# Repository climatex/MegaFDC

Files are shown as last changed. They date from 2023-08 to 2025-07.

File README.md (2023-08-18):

# MegaFDC
Arduino Mega2560 floppy disk controller.

Supports 8" / 5.25" / 3.5" drives (PS/2 2.88MB included) with custom geometry, FAT12 and experimental CP/M.

Interfaces via USB/RS232, also through keyboard and display.

# More information
Check out my [website article](http://boginjr.com/it/hw/megafdc) to learn more!

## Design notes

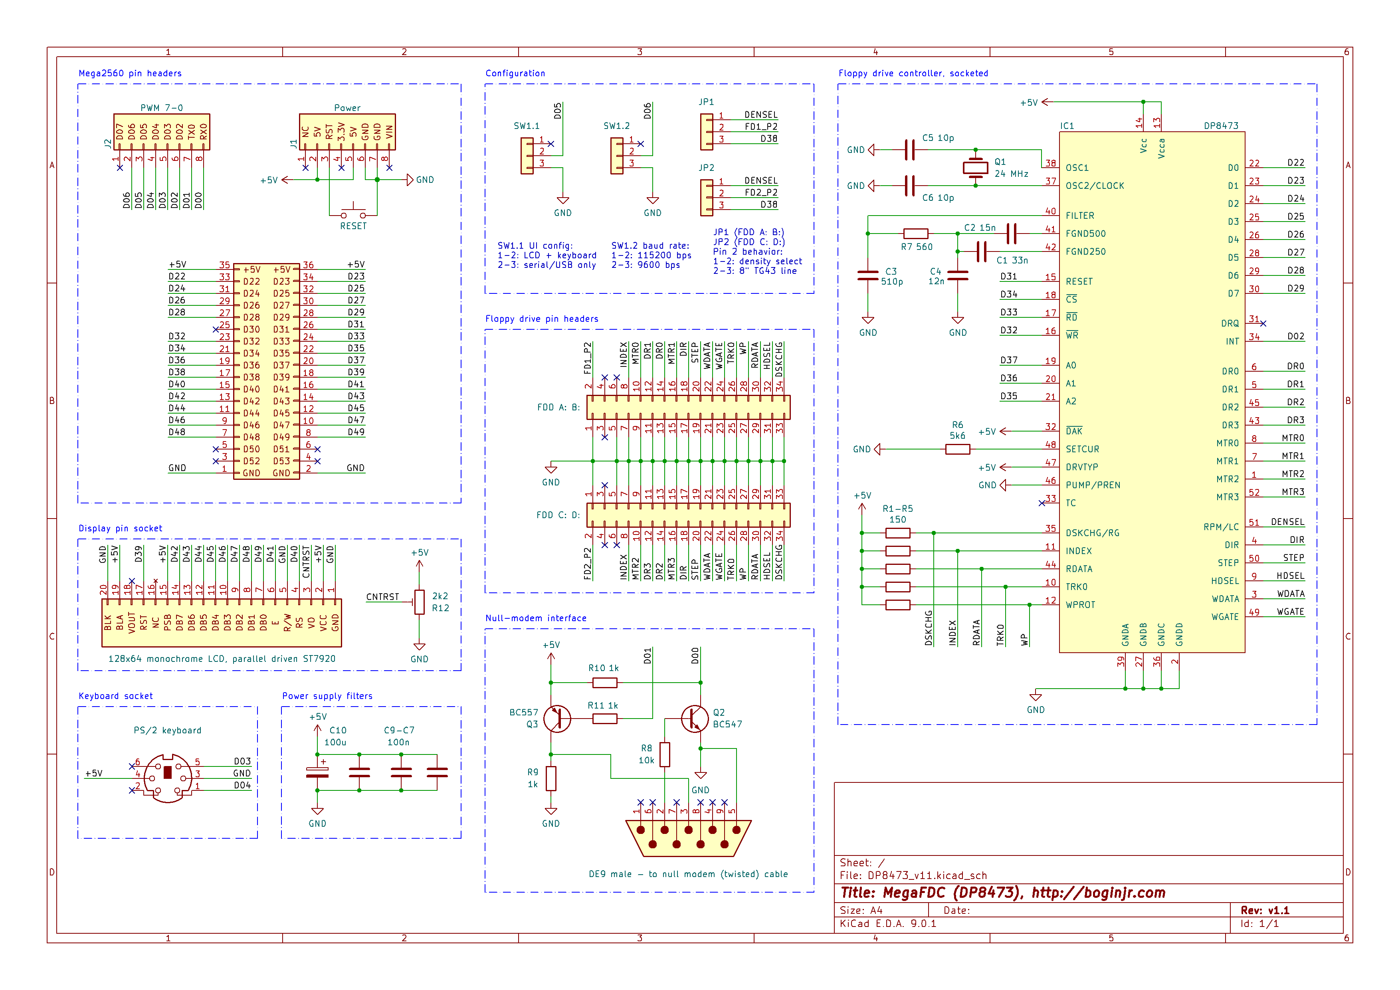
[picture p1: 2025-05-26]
Boards/DP8473/DP8473_v11.png

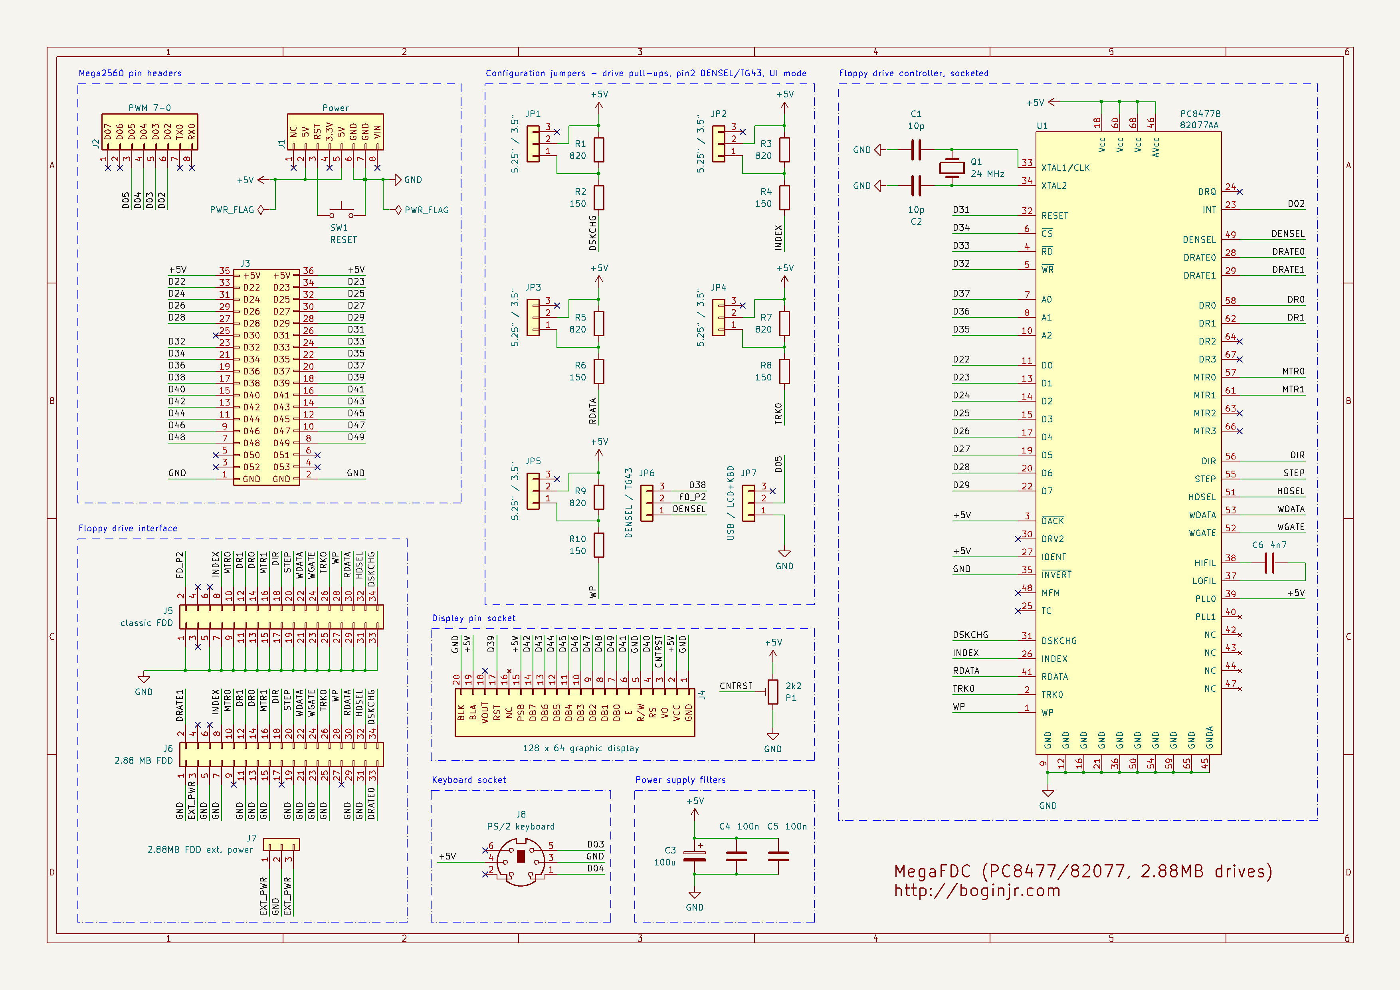
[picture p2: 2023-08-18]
Boards/PC8477/PC8477.png

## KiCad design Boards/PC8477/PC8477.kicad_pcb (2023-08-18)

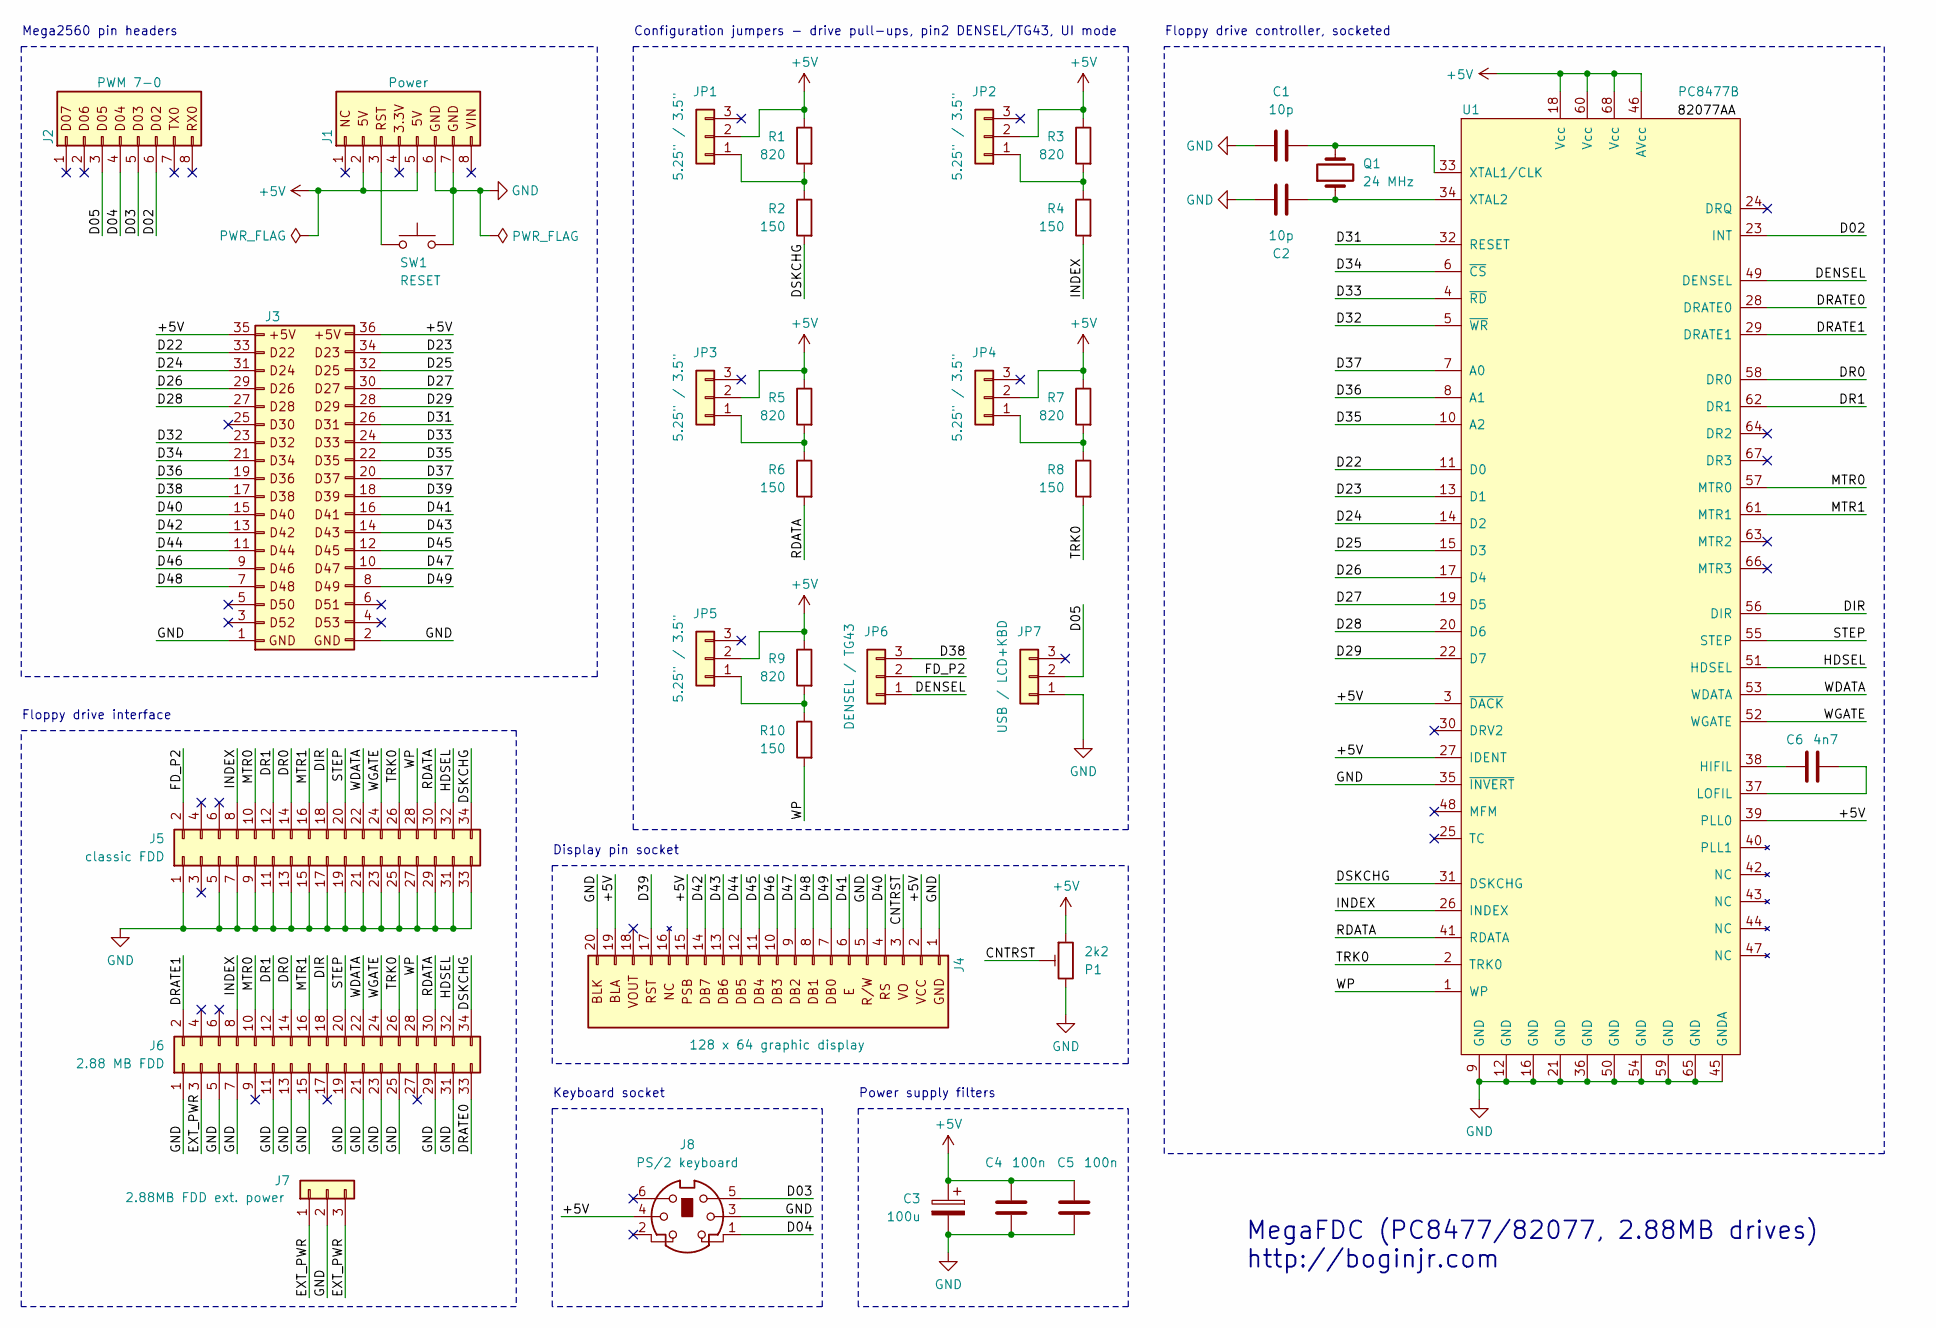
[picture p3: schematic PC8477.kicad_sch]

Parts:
C1, C2: 10p; C_Disc_D7.5mm_W2.5mm_P5.00mm
C3: 100u; CP_Radial_D6.3mm_P2.50mm
C4, C5: 100n; C_Disc_D7.5mm_W2.5mm_P5.00mm
C6: 4n7; C_Disc_D7.5mm_W2.5mm_P5.00mm
J1: Power; PinHeader_1x08_P2.54mm_Vertical
J2: PWM 7-0; PinHeader_1x08_P2.54mm_Vertical
J3: Digital; PinHeader_2x18_P2.54mm_Vertical
J4: 128 x 64 graphic display; PinSocket_1x20_P2.54mm_Vertical
J5: classic FDD; PinHeader_2x17_P2.54mm_Vertical
J6: 2.88 MB FDD; PinHeader_2x17_P2.54mm_Vertical
J7: 2.88MB FDD ext. power; PinHeader_1x03_P2.54mm_Vertical
J8: PS/2 keyboard; Mini_DIN6_Female_THT
JP1, JP2, JP3, JP4, JP5: 5.25" / 3.5"; PinHeader_1x03_P2.54mm_Vertical
JP6: DENSEL / TG43; PinHeader_1x03_P2.54mm_Vertical
JP7: USB / LCD+KBD; PinHeader_1x03_P2.54mm_Vertical
P1: 2k2; Potentiometer_Bourns_3386P_Vertical
Q1: 24 MHz; Crystal_HC49-U_Vertical
R1, R3, R5, R7, R9: 820; R_Axial_DIN0207_L6.3mm_D2.5mm_P10.16mm_Horizontal
R2, R4, R6, R8, R10: 150; R_Axial_DIN0207_L6.3mm_D2.5mm_P10.16mm_Horizontal
SW1: RESET; SW_PUSH_6mm
U1: PC8477B; PLCC-68_THT-Socket

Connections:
+5V: C3.1, C4.1, C5.1, J1.2, J1.5, J3.35, J3.36, J4.2, J4.15, J4.19, J8.4, JP1.2, JP2.2, JP3.2, JP4.2, JP5.2, P1.1, R1.1, R3.1, R5.1, R7.1, R9.1, U1.3 (~DACK), U1.18 (Vcc), U1.27 (IDENT), U1.39 (PLL0), U1.46 (AVcc), U1.60 (Vcc), U1.68 (Vcc)
/CNTRST: J4.3, P1.2
/D02: J2.6, U1.23 (INT)
/D03: J2.5, J8.5
/D04: J2.4, J8.1
/D05: J2.3, JP7.2
/D22: J3.33, U1.11 (D0)
/D23: J3.34, U1.13 (D1)
/D24: J3.31, U1.14 (D2)
/D25: J3.32, U1.15 (D3)
/D26: J3.29, U1.17 (D4)
/D27: J3.30, U1.19 (D5)
/D28: J3.27, U1.20 (D6)
/D29: J3.28, U1.22 (D7)
/D31: J3.26, U1.32 (RESET)
/D32: J3.23, U1.5 (~WR)
/D33: J3.24, U1.4 (~RD)
/D34: J3.21, U1.6 (~CS)
/D35: J3.22, U1.10 (A2)
/D36: J3.19, U1.8 (A1)
/D37: J3.20, U1.7 (A0)
/D38: J3.17, JP6.3
/D39: J3.18, J4.17
/D40: J3.15, J4.4
/D41: J3.16, J4.6
/D42: J3.13, J4.14
/D43: J3.14, J4.13
/D44: J3.11, J4.12
/D45: J3.12, J4.11
/D46: J3.9, J4.10
/D47: J3.10, J4.9
/D48: J3.7, J4.8
/D49: J3.8, J4.7
/DENSEL: JP6.1, U1.49 (DENSEL)
/DIR: J5.18, J6.18, U1.56 (DIR)
/DR0: J5.14, J6.14, U1.58 (DR0)
/DR1: J5.12, J6.12, U1.62 (DR1)
/DRATE0: J6.33, U1.28 (DRATE0)
/DRATE1: J6.2, U1.29 (DRATE1)
/DSKCHG: J5.34, J6.34, R2.2, U1.31 (DSKCHG)
/EXT_PWR: J6.3, J7.1, J7.3
/FD_P2: J5.2, JP6.2
/HDSEL: J5.32, J6.32, U1.51 (HDSEL)
/INDEX: J5.8, J6.8, R4.2, U1.26 (INDEX)
/MTR0: J5.10, J6.10, U1.57 (MTR0)
/MTR1: J5.16, J6.16, U1.61 (MTR1)
/RDATA: J5.30, J6.30, R6.2, U1.41 (RDATA)
/STEP: J5.20, J6.20, U1.55 (STEP)
/TRK0: J5.26, J6.26, R8.2, U1.2 (TRK0)
/WDATA: J5.22, J6.22, U1.53 (WDATA)
/WGATE: J5.24, J6.24, U1.52 (WGATE)
/WP: J5.28, J6.28, R10.2, U1.1 (WP)
GND: C1.1, C2.1, C3.2, C4.2, C5.2, J1.6, J1.7, J3.1, J3.2, J4.1, J4.5, J4.20, J5.1, J5.5, J5.7, J5.9, J5.11, J5.13, J5.15, J5.17, J5.19, J5.21, J5.23, J5.25, J5.27, J5.29, J5.31, J5.33, J6.1, J6.5, J6.7, J6.11, J6.13, J6.15, J6.19, J6.21, J6.23, J6.25, J6.29, J6.31, J7.2, J8.3, J8.SH1, J8.SH2, J8.SH3, JP7.1, P1.3, SW1.1, U1.9 (GND), U1.12 (GND), U1.16 (GND), U1.21 (GND), U1.35 (~INVERT), U1.36 (GND), U1.45 (GNDA), U1.50 (GND), U1.54 (GND), U1.59 (GND), U1.65 (GND)
unnamed: J1.3, SW1.2
unnamed: JP1.1, R1.2, R2.1
unnamed: JP2.1, R3.2, R4.1
unnamed: JP3.1, R5.2, R6.1
unnamed: JP4.1, R7.2, R8.1
unnamed: JP5.1, R9.2, R10.1
unnamed: C6.2, U1.38 (HIFIL)
unnamed: C6.1, U1.37 (LOFIL)
unnamed: C1.2, Q1.2, U1.33 (XTAL1/CLK)
unnamed: C2.2, Q1.1, U1.34 (XTAL2)

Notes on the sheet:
Configuration jumpers - drive pull-ups, pin2 DENSEL/TG43, UI mode
Keyboard socket
Floppy drive interface
Power supply filters
MegaFDC (PC8477/82077, 2.88MB drives) http://boginjr.com
Display pin socket
Floppy drive controller, socketed
Mega2560 pin headers

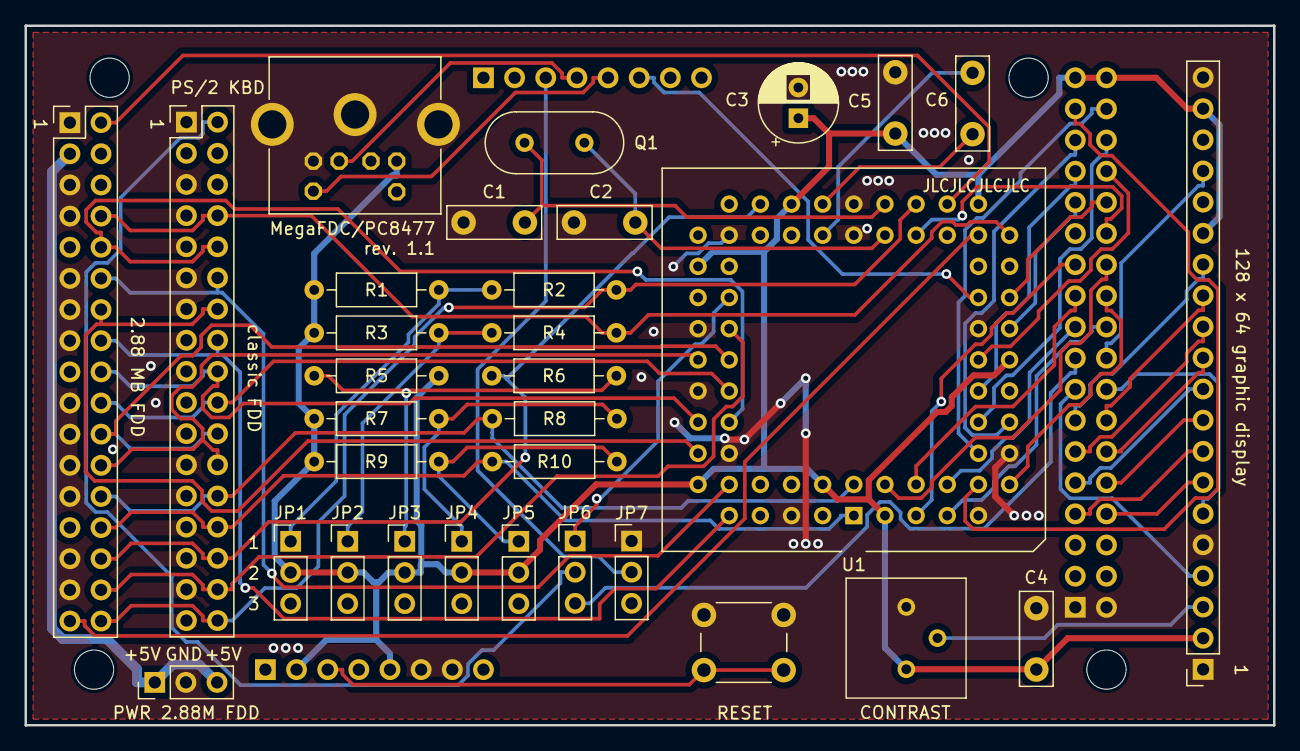
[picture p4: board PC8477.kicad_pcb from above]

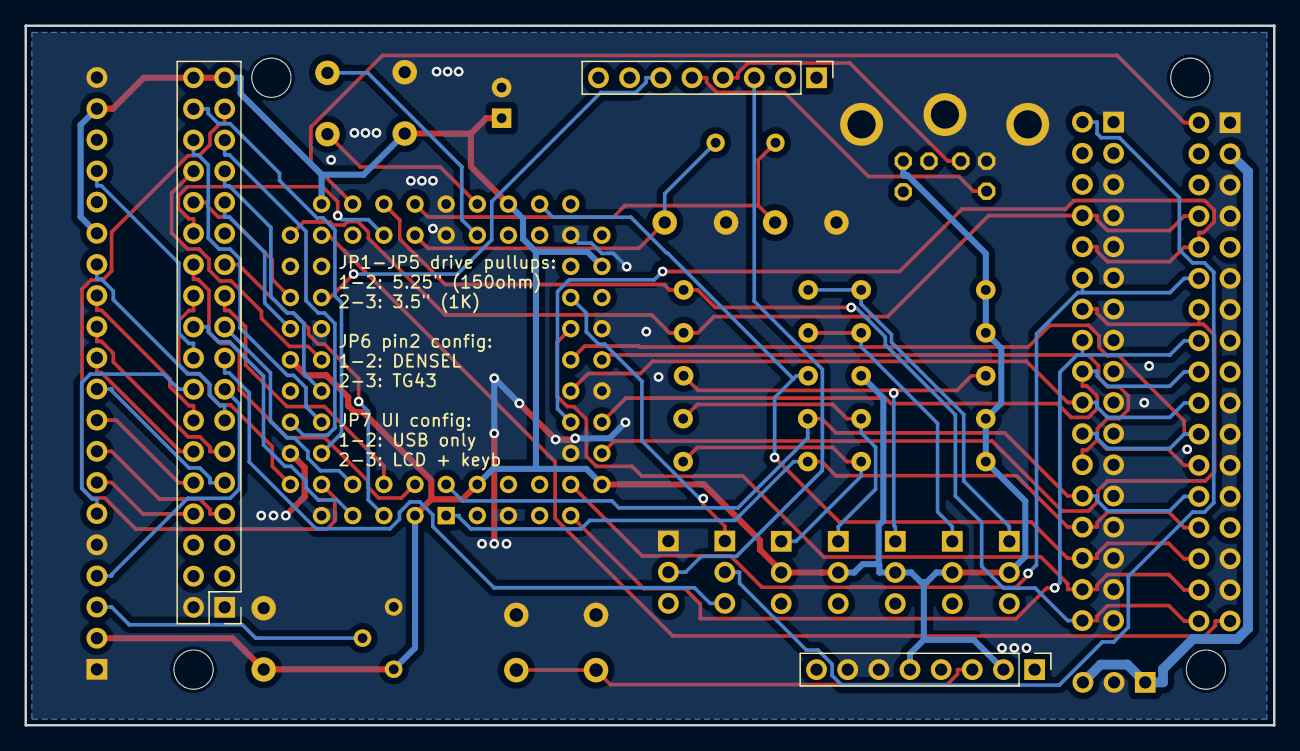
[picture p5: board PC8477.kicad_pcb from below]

Board: 2 copper layers, 101.8 x 57.0 mm, 39 parts (3 on the bottom side), 63 nets.

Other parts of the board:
MH1, MH2, MH5, MH6: MountingHole_3.2mm

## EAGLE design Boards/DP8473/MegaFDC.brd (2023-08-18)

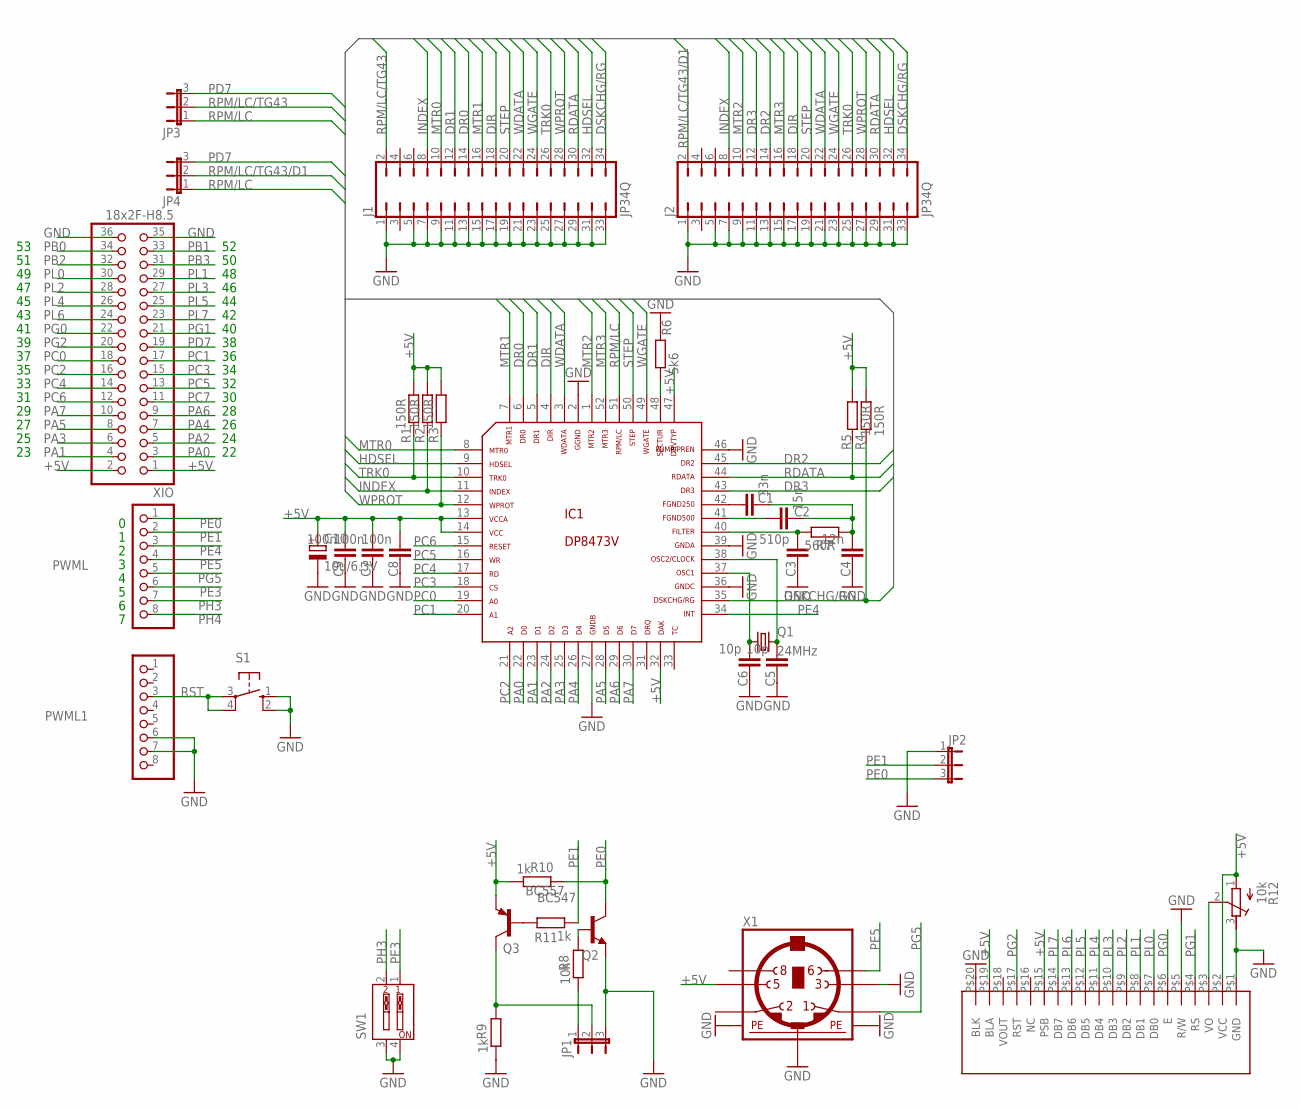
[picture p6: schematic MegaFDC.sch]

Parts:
C1: 33n; C025-025X050
C2: 15n; C025-025X050
C3: 510p; C025-025X050
C4: 12n; C025-025X050
C5, C6: 10p; C025-025X050
C7, C8, C9: 100n; C050-025X075
C10: 10u/6.3V; B45181A
IC1: DP8473V; S52
J1, J2: JP34Q
JP1, JP2, JP3, JP4: JP2E; JP2
PWML, PWML1: 8x1F-H8.5; 1X08
Q1: 24MHz; HC49/S
Q2: BC547; TO92S
Q3: BC557; TO92-EBC
R1, R2, R3, R4, R5: 150R; 0207/7
R6: 5k6; 0207/7
R7: 560R; 0207/7
R8: 10k; 0207/7
R9, R10, R11: 1k; 0207/7
R12: 10k; RTRIM3296Y
S1: 10-XX; B3F-10XX
SW1: DIP2X; EDG-02
U$1: W12864
X1: MINI_DIN_6; M_DIN6
XIO: 18x2F-H8.5; 2X18

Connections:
+5V: C7.2, C8.2, C9.2, C10.+, IC1.13, IC1.14, IC1.32, IC1.47, Q3.E, R1.2, R2.2, R3.2, R4.2, R5.2, R10.1, R12.1 (A), U$1.P$2 (VCC), U$1.P$15 (PSB), U$1.P$19 (BLA), X1.5, XIO.1, XIO.2
DIR: IC1.4, J1.18, J2.18
DR0: IC1.6, J1.14
DR1: IC1.5, J1.12
DR2: IC1.45, J2.14
DR3: IC1.43, J2.12
DSKCHG/RG: IC1.35, J1.34, J2.34, R4.1
GND: C3.1, C4.1, C5.1, C6.1, C7.1, C8.1, C9.1, C10.-, IC1.2, IC1.27, IC1.36, IC1.39, IC1.46, J1.1, J1.5, J1.7, J1.9, J1.11, J1.13, J1.15, J1.17, J1.19, J1.21, J1.23, J1.25, J1.27, J1.29, J1.31, J1.33, J2.1, J2.5, J2.7, J2.9, J2.11, J2.13, J2.15, J2.17, J2.19, J2.21, J2.23, J2.25, J2.27, J2.29, J2.31, J2.33, JP1.3, JP2.1, PWML1.6, PWML1.7, Q2.1 (E), R6.2, R9.1, R12.3 (E), S1.1 (S), S1.2 (S1), SW1.3, SW1.4, U$1.P$1 (GND), U$1.P$5 (R/W), U$1.P$20 (BLK), X1.3, X1.SH1 (PE1), X1.SH2 (PE2), X1.SH3 (PE3), XIO.35, XIO.36
HDSEL: IC1.9, J1.32, J2.32
INDEX: IC1.11, J1.8, J2.8, R2.1
MTR0: IC1.8, J1.10
MTR1: IC1.7, J1.16
MTR2: IC1.1, J2.10
MTR3: IC1.52, J2.16
unnamed: C1.1, IC1.42
unnamed: C2.1, IC1.41
unnamed: C1.2, C2.2, C4.2, R7.2
unnamed: C3.2, IC1.40, R7.1
unnamed: C5.2, IC1.38, Q1.2
unnamed: IC1.48, R6.1
unnamed: C6.2, IC1.37, Q1.1
unnamed: JP1.1, R8.1
unnamed: Q2.2 (B), R8.2
unnamed: JP1.2, Q3.C, R9.2
unnamed: Q3.B, R11.2
unnamed: R12.2 (S), U$1.P$3 (VO)
PA0: IC1.22, XIO.3
PA1: IC1.23, XIO.4
PA2: IC1.24, XIO.5
PA3: IC1.25, XIO.6
PA4: IC1.26, XIO.7
PA5: IC1.28, XIO.8
PA6: IC1.29, XIO.9
PA7: IC1.30, XIO.10
PB0: XIO.34
PB1: XIO.33
PB2: XIO.32
PB3: XIO.31
PC0: IC1.19, XIO.18
PC1: IC1.20, XIO.17
PC2: IC1.21, XIO.16
PC3: IC1.18, XIO.15
PC4: IC1.17, XIO.14
PC5: IC1.16, XIO.13
PC6: IC1.15, XIO.12
PC7: XIO.11
PD7: JP3.3, JP4.3, XIO.19
PE0: JP2.3, PWML.1, Q2.3 (C), R10.2
PE1: JP2.2, PWML.2, R11.1
PE3: PWML.6, SW1.1
PE4: IC1.34, PWML.3
PE5: PWML.4, X1.6
PG0: U$1.P$6 (E), XIO.22
PG1: U$1.P$4 (RS), XIO.21
PG2: U$1.P$17 (RST), XIO.20
PG5: PWML.5, X1.1
PH3: PWML.7, SW1.2
PH4: PWML.8
PL0: U$1.P$7 (DB0), XIO.30
PL1: U$1.P$8 (DB1), XIO.29
PL2: U$1.P$9 (DB2), XIO.28
PL3: U$1.P$10 (DB3), XIO.27
PL4: U$1.P$11 (DB4), XIO.26
PL5: U$1.P$12 (DB5), XIO.25
PL6: U$1.P$13 (DB6), XIO.24
PL7: U$1.P$14 (DB7), XIO.23
RDATA: IC1.44, J1.30, J2.30, R5.1
RPM/LC: IC1.51, JP3.1, JP4.1
RPM/LC/TG43: J1.2, JP3.2
RPM/LC/TG43/D1: J2.2, JP4.2
RST: PWML1.3, S1.3, S1.4 (P1)
STEP: IC1.50, J1.20, J2.20
TRK0: IC1.10, J1.26, J2.26, R1.1
WDATA: IC1.3, J1.22, J2.22
WGATE: IC1.49, J1.24, J2.24
WPROT: IC1.12, J1.28, J2.28, R3.1

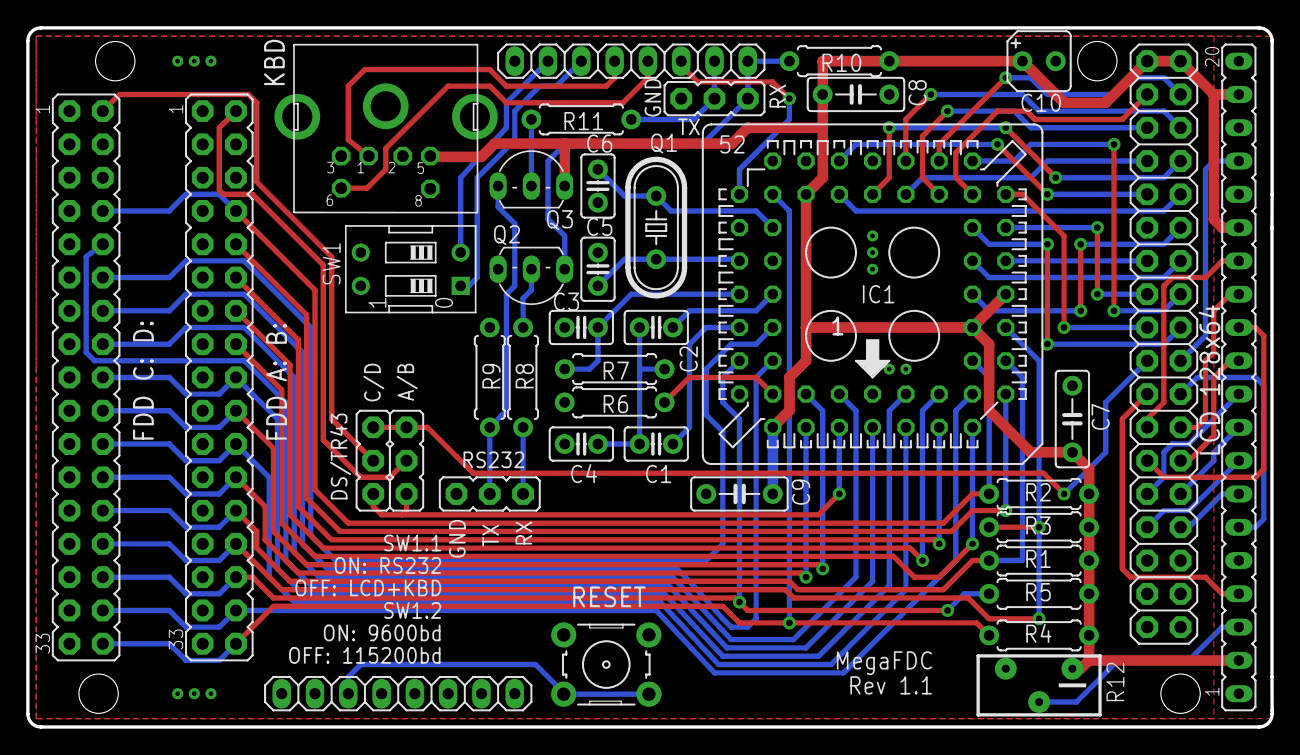
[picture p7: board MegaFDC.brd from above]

Board: 2 copper layers, 94.9 x 53.3 mm, 39 parts (0 on the bottom side), 70 nets.

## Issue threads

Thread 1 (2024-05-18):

mb8877 ???

gilmod714, 2024-05-18:
Hello Jozef,

Could you please help me adapt this to a different FDC chip mb8877?  data-separater(wd9216) and (7406) inv-buffer? .. I'm trying to adapt this project to my 8bit-computer Z80 FDC controller and see if that'll work as an addition to the real hardware .. yes, I know this is NOT a one-chip solution like yours, but these are the chips I already have in my pile  .. and also,  I can't get the specific chip(s) you have in your design .. (too expensive to mail-order from where I live) .. Thank you!

I've emailed you earlier.. Gilmod714@yahoo.com , with your reply below :)

*
*
*

gilmo says:
[10. April 2024 at 04:56](http://boginjr.com/it/hw/megafdc/#comment-17689)

could this be interfaced to a Z80 bus, as a full fdc , for 8 bit computers ?!
[Reply](http://boginjr.com/it/hw/megafdc/?replytocom=17689#respond)

    Jozef says:
    [10. April 2024 at 10:02](http://boginjr.com/it/hw/megafdc/#comment-17690)

    Why would you do that? If you have hardware knowledge of your platform and know how to code, you can already program the FDC chip with your Z80 directly (with some TTL glue logic involved). Of course you could use the source code of MegaFDC as an inspiration to see how the communication between the CPU and the FDC is done.
    But to answer your question, yes, it can be done. Experiment!

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

[Schematic_FC05-ARDUINO_2024-05-21.pdf](https://github.com/climatex/MegaFDC/files/15381784/Schematic_FC05-ARDUINO_2024-05-21.pdf)

.. I have also added 4Mhz PWM on pin11 of the MEGA (simulating the Z80 bus freq for now) to feed into 8877 & 9216 in "main.cpp" , but still need more code-tweaks for MOTOR &  SSEL signals and also (A0,A1) instead of 3 address lines ..

//MAIN.CPP
// MegaFDC (c) 2023 J. Bogin, http://boginjr.com
// Entry point

#include "config.h"

// user interface
Ui* ui = NULL;

// floppy disk controller
FDC* fdc = NULL;

// 4Mhz pwm
const int freqOutputPin = 11;   // OC1A output pin (Arduino Mega2560)
const int ocr1aval  = 1;   //0,1,3,7 --- 0=8mhz, 1=4mhz, 3=2mhz , 7=1mhz

void setup()
{
    // 4Mhz pwm
    pinMode(freqOutputPin, OUTPUT);
    TCCR1A = ( (1 << COM1A0));
    TCCR1B = ((1 << WGM12) | (1 << CS10));
    TIMSK1 = 0;
    OCR1A = ocr1aval;

//org
  ui = Ui::get();
  fdc = FDC::get();
  InitializeDrives();
}

void loop()
{
  ProcessCommands();
}

climatex, 2024-05-21:
I'm afraid you won't be able to even utilize the data communication routines of MegaFDC. The MB8877 does not follow the NEC uPD765 (PC-compatible FDC) commands syntax which MegaFDC is reliant on, so it's not a simple matter of adapting the circuit. Your best bet here is to start from scratch, or fork the project and rewrite all fdc.cpp routines to fit.
If you have old ISA PC cards you can sometimes salvage PC floppy controller chips off them as I did, there's no need to mail order anything.

gilmod714, 2024-05-21:
ok , I kinda hoped it would be an easy task to do,  but I was unaware of the major differences between the two controller chips and the major code-rewrite required. Thx Jozef

Closed 2024-05-21.

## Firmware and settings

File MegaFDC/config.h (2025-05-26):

// MegaFDC (c) 2023-2025 J. Bogin, http://boginjr.com
// Build and wiring configuration

#pragma once

// begin conditional build options:
// comment out line to disable display and keyboard support
#define UI_ENABLED

// by default, build regular MegaFDC with command line and filesystem support
// to work as an IMD imager, uncomment the following define
//#define BUILD_IMD_IMAGER
// end conditional build options.

/*

  Default pin assignments to a Mega2560 rev3 board
  FDC board schematic see http://boginjr.com/it/hw/megafdc/
  PS/2 2.88MB support see http://boginjr.com/it/hw/ps2/
  IMD mode see            http://boginjr.com/it/hw/imd/
  
  optional AT/PS2/switchable USB keyboard, pinout configurable
  Vcc, GND              (Vcc, GND)
  CLOCK (KEYB_CLK)      (PORTE5: D03) reconfigure note: must be interrupt capable
  DATA (KEYB_DATA)      (PORTG5: D04)
   
  optional 128x64 parallel display (ST7920, others can be used too). Pinout configurable
  Vcc, GND              (Vcc, GND)
  BLK                   (GND)
  BLA                   (Vcc, break to turn off backlight)
  PSB                   (Vcc, for parallel mode)  
  V0 contrast adjust    (10K trimpot taper, trimpot ends Vcc, GND)
  D0-7                  (PORTL0-7: D49, D48, D47, D46, D45, D44, D43, D42)
  E, RS, RST            (PORTG0-2: D41, D40, D39)  
  
  optional TG43 (/REDWC) line handling: reduced write current past track 43 for 8" drives
  TG43                  (PORTD7: D38)  
  
  optional switch/jumper to communicate only via serial interface even when built with UI_ENABLED
  1st contact           (PORTE3: D05)
  2nd contact           (GND)
  
  optional switch/jumper to switch the communication rate from 115200 bps to 9600 bps
  1st contact           (PORTG5: D06)
  2nd contact           (GND)
   
  Floppy disk controller (pinout fixed)
  Vcc, GND              (Vcc, GND)
  INT                   (PORTE4: D02)
  D0-D7                 (PORTA0-7: D22, D23, D24, D25, D26, D27, D28, D29)
  A0-A2                 (PORTC0-2: D37, D36, D35)
  /CS, /RD, /WR, RESET: (PORTC3-6: D34, D33, D32, D31)

*/

// configurable Dxx pins
#define DISP_D0                49   // display parallel data lines 0 to 7
#define DISP_D1                48
#define DISP_D2                47
#define DISP_D3                46
#define DISP_D4                45
#define DISP_D5                44
#define DISP_D6                43
#define DISP_D7                42
#define DISP_E                 41   // display enable
#define DISP_RS                40   // register select
#define DISP_RST               39   // display reset
#define KEYB_CLK               3    // CLK must be hardware interrupt pin, 2 is wired to the FDC
#define KEYB_DATA              4
#define SWITCH_DISABLE_UI      5    // ground this pin to talk via serial even if built with UI_ENABLED
#define SWITCH_9600BPS_RATE    6    // ground this pin to slow down the serial comm from 115200 to 9600

// UI defines
//#define CLEAR_SCREEN_SERIAL  1                  // uncomment for ui->print("") function (which clears the LCD) to also clear the terminal over serial comm
#define UI_FONT                u8g2_font_4x6_mr   // 128 x 64 display with a 4x6 monospace font
#define CHAR_WIDTH             4
#define CHAR_HEIGHT            7                  // height+1 for one extra empty line between lines + blinking cursor
#define MAX_COLS               32                 // maximum characters per line with chosen font
#define MAX_LINES              9                  // maximum lines
#define MAX_CHARS              MAX_COLS*MAX_LINES // maximum characters shown at once on said display; MAX_CHARS+1 size of print buffer
#define MAX_COMMAND_PROMPT_LEN 50                 // maximum number of characters allowed when prompted for input, MAX+1 size of prompt buffer, min. 25
#define MAX_PROGMEM_STRING_LEN 50                 // maximum number of characters for each string in PROGMEM, MAX+1 size of buffer for pgm_read_ptr()

// FDC defines
#ifndef BUILD_IMD_IMAGER                          // - normal MegaFDC:
  #define SECTOR_BUFFER_SIZE   3072               // disk sector I/O buffer, needs to be divisible by 128
                                                  // min. 512B for FAT, and 1024 for 8" drive support and XMODEM-1K
                                                  // 1.44M disk image transfer thru XMODEM-1K vs bufsize: 3072 (3:45), 1024 (5:20), 512 (XMODEM-128, 10min)
#else                                             // - IMD imager mode, works sector-by-sector:
  #define SECTOR_BUFFER_SIZE   2048               // larger sectors (4K, 8K) can only be formatted/verified
#endif

#define IO_TIMEOUT             8500000            // number of (32bit) decrements in a while loop checking a response from the FDC; about 5 seconds 
#define DISK_OPERATION_RETRIES 5                  // number of retries per disk operation (at least 5)
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

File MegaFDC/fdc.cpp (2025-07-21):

// MegaFDC (c) 2023-2025 J. Bogin, http://boginjr.com
// Floppy disk controller interface
// Software compatible with a NEC uPD765 or any other PC FDC

#include "config.h"

// global disk I/O buffer
volatile BYTE g_rwBuffer[SECTOR_BUFFER_SIZE];
volatile BYTE intType = 0;
volatile BYTE intFired = 0;
volatile WORD dataPos = 0;

// turn off floppy motor timer, if motor on and FDC idle for more than 2 seconds
ISR(TIMER5_COMPA_vect)
{
  static BYTE timerCount = 0;
  static FDC* fdc = FDC::get();
  
  if (fdc->isIdle())
  {  
    if (fdc->isMotorOn())
    { 
      if (timerCount > 2)
      {
        fdc->motorOff();
        timerCount = 0;
      }
      else
      {
        timerCount++;
      }
    }
  }
  
  // not idle
  else
  {
    timerCount = 0;
  }
}

// singleton
FDC::FDC()
{   
  // means: floppy controller successfully reset and drive can be seeked to cylinder 0
  m_initialized = false;
  
  m_params = NULL;  
  m_lastError = false;
  m_motorOn = false;
  m_noDiskInDrive = false;
  m_diskWriteProtected = false;
  m_diskChangeInquired = false;
  m_idle = true;
  m_silentOnTrivialError = false;
  m_controlMark = false;
  
  // no special features support determined yet
  m_specialFeatures = 0;
   
  // current physical CHS values
  m_currentCylinder = 0;
  m_currentHead = 0;
  m_currentSector = 1;  
   
  // initialize FDC by doing a hardware reset + also set port directions to default:
  // data lines (PORTA) set as output, address lines + RESET/RD/WR/TC (PORTC) set as output
  cli();
  DDRC = 0xFF;
  DDRA = 0xFF;
  PORTA = 0;
  
  // TG43 (on PD7) off by default
  PORTD |= 0x80;

  // pull /CS, /RD, /WR high, RESET high for some good 30us
  PORTC = 0x78;  
  DELAY_CYCLES(500);
  
  // flip RESET low - reset over; /CS low (chip selected)
  PORTC ^= 0x48;
   
  // setup Mega2560 Timer5 to automatically turn off floppy motor
  // freq. = 16MHz / CMR * prescaler
  // 1Hz = 16000000/15624*1024
  TCCR5A = 0;
  TCCR5B = 0;
  TCNT5 = 0;

  // CMR
  OCR5A = 15624; 
  
  // 1024 prescaler with CTC
  TCCR5B |= (1 << WGM52) | (1 << CS52) | (1 << CS50);
  
  // enable timer (interrupts still disabled for now)
  TIMSK5 |= (1 << OCIE5A);
  
  // attach FDC INT signal (pin 2, PORTE4)
  pinMode(2, INPUT);
  setInterrupt();
    
  // enable interrupts
  sei();
}

// get data from DTR
BYTE FDC::getData()
{  
  //read data from FDC DTR with handshaking and timeout
  DWORD timeout = IO_TIMEOUT;
  
  while (--timeout)
  {
    // inspect main status register, receive byte only if RQM=1 and direction is FDC->AVR
    if ((readRegister(MSR) & 0xC0) == 0xC0)
    {
      return readRegister(DTR);
    }
  }
  
  // no picture, no sound
  m_idle = true;
  fatalError(Progmem::errRQMTimeout);
  
  return 0; // won't return - just to keep compiler happy
}

void FDC::sendData(BYTE data)
{  
  //send data to FDC DTR with handshaking and timeout
  DWORD timeout = IO_TIMEOUT;
  
  while (--timeout)  
  {
    // send byte only if RQM=1 and direction is AVR->FDC
    if ((readRegister(MSR) & 0xC0) == 0x80)
    {
      writeRegister(DTR, data);
      return;
    }
  }
  
  // same as above
  m_idle = true;
  fatalError(Progmem::errRQMTimeout);
}

// waits until interrupt from FDC
void FDC::waitForINT()
{
  DWORD timeout = IO_TIMEOUT;

  while (--timeout)
  {
    if (intFired)
    {
      // interrupt as a command result needs to be "sensed" with cmd 0x8
      intFired = 0;
      m_lastError = false;
      return;        
    }
  }
  
  // the FDC is deaf as a post
  m_idle = true;
  fatalError(Progmem::errRQMTimeout);
}

// similar to waitForINT; allows continuing after timeout
bool FDC::waitForDATA()
{
  DWORD timeout = IO_TIMEOUT;
  
  while(--timeout)
  {
    if (intFired)
    {   
      intFired = 0; //reset flag
      return true;
    }
  }
    
  return false;
}

void FDC::sendCommand(BYTE command)
{
  // calls sendData for main commands, erases MFM flag if FM on
  if (m_params && m_params->FM)
  {
    sendData(command & 0xBF);
  }
  else
  {
    sendData(command);
  }
}

void FDC::resetController()
{ 
  m_idle = false;
  
  // reset interrupt handler
  cli();
  detachInterrupt(digitalPinToInterrupt(2));
  intType = 0;
  setInterrupt();
  sei();
  
  // prepare drive select and motor on bits
  BYTE driveSelect = 0;
  BYTE motorOn = 0;
  if (m_params)
  {
    driveSelect = m_params->DriveNumber & 0x03;
    motorOn = 1 << (m_params->DriveNumber + 4);
  }
  
  // software controller reset by bit 2=0 in DCR (keep motor on if retrying)
  // interrupts off, all drives unselected
  writeRegister(DCR, m_motorOn ? motorOn : 0);  
  DELAY_CYCLES(500);
  
  // interrupts on, reset off, drive select (motor on conditions same as above)
  writeRegister(DCR, m_motorOn ? motorOn | driveSelect | 0x0C : driveSelect | 0x0C);
  waitForINT();
    
  // call Sense interrupt status command (0x8) after a reset 3 times (drive polling)
  for (int count = 0; count < 3; count++)
  {
    sendCommand(8);
    getData(); // ST0, unused
    getData(); // current track number, unused
  }
  
  // determine special support - try out controller capabilities: CONFIGURE and PERPENDICULAR commands
  // the former to configure FIFO enabled to offer 1Mbps mode, the latter to offer 2.88MB drives
  // both commands have no result phase - if we get one, it means the FDC did not understand the command  
  // start with 0x13 - Configure
  sendCommand(0x13);
  
  // wait for RQM response after sending
  while (!(readRegister(MSR) & 0x80)) {};
  
  // direction is now FDC->AVR instead of AVR->FDC? this means the FDC wants to tell us something
  if ((readRegister(MSR) & 0xC0) == 0xC0)
  {
    // and we know what it is: 0x80 Invalid command in ST0, read it and trash it
    getData();
  }
  
  // no result phase - command understood and can be specified
  else
  {
    sendData(0); // unused
    sendData(3); // configure: implied seek off, FIFO on, with 4 bytes threshold
    sendData(0); // starting track for write precompensation - unused, default
    
    m_specialFeatures |= SUPPORT_1MBPS;
  }
  
  // 0x12 Perpendicular mode, same check as above
  sendCommand(0x12);
  while (!(readRegister(MSR) & 0x80)) {};
  if ((readRegister(MSR) & 0xC0) == 0xC0)
  {
    getData();
  }
  
  else
  {
    sendData(0x80); // command understood, all 4 drives initialized as normal for now
    m_specialFeatures |= SUPPORT_PERPENDICULAR;
  }
  
  // if setActiveDrive was not called yet, return
  if (!m_params)
  {
    return;
  }
  
  // set FDC communication rate and stepper motor timings
  setCommunicationRate();
  
  // recalibrate command required to initialize disk operations
  m_idle = true;
}
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

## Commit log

2023-07-04 Handle TG43 on PD7, wait 2 cycles for FDC, CP/M root dir bugfixes
    [fdc.cpp]
2023-08-18 Add boards and schematics, FIFO buffer support, perpendicular recording, bugfixes
    [DP8473_v11.kicad_sch, MegaFDC.brd, MegaFDC.sch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]
2024-11-24 Add ImageDisk (IMD) support, bugfixes
    [config.h]
2024-11-28 Set stepper to 16ms for an 8" CDC drive, bugfix in DRIVPARM
    [fdc.cpp]
2025-03-30 Improve interleave detection in IMD mode; bugfixes
    [config.h]
2025-05-26 Build 26th of May 2025 changes:
    - UI with LCD output now doesn't require a physical keyboard,
    - TYPEINTO command opens files with append instead of truncate,
    - bugfix in the DELAY_MS macro,
    - DP8473 Kicad schematic parts numbers reordered to match the Eagle PCB.
    [DP8473_v11.kicad_sch]
2025-06-26 Build 26th of June 2025 changes:
    - IMD mode: sector 0 compatibility,
    - IMD mode format command: customizable starting sector,
    - both modes: better distinguish between track and a cylinder in code and strings.
2025-07-21 Classic mode: bugfix in getMaximumSectorCount()
    [fdc.cpp]
